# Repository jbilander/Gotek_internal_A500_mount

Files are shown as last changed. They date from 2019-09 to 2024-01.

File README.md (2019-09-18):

# Gotek_internal_A500_mount
An internal Gotek mounting bracket for the Amiga 500 designed in DesignSpark Mechanical 4.0

I was not happy with the internal mount I got when buying a Gotek floppy emulator for the Amiga 500. I did a respin to better position the usb socket and the oled display, and to fit both the revision A and B of the A500/500+ Cases. This is the result. You don't have to modify your case in any way for the Gotek to fit with this mount, and the standard 34-pin floppy cable can be used as it just about reaches the Gotek. It sits a few mm back compared to the other mount.

<a href="images/Gotek_internal_A500_mount_pic1.jpg">
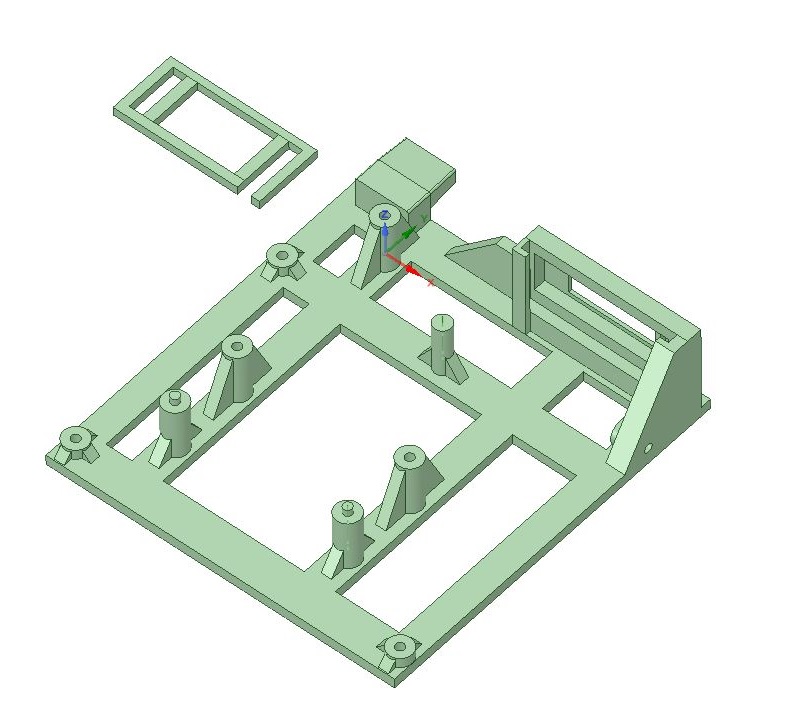
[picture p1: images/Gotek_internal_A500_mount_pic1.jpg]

</a>

***

To 3d-print this model it takes about 5 hours with Standard Quality 0.2mm, 60% infill, using an Ender 3 Pro printer. It uses around 12 meters Ø1.75mm (35 grams) of filament.

<a href="images/Gotek_internal_A500_mount_pic2.jpg">
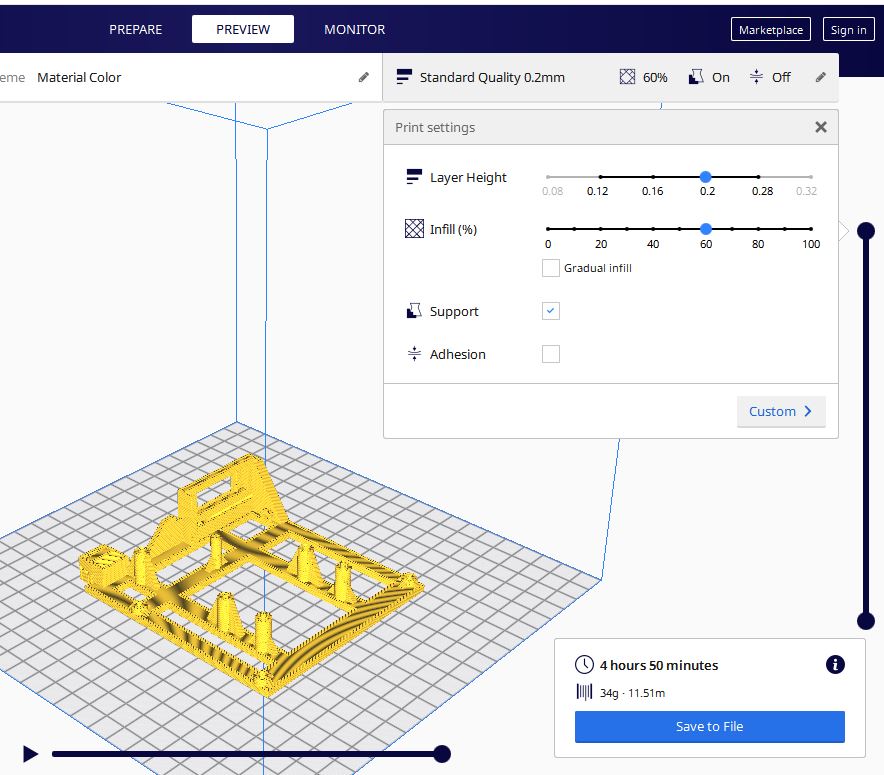
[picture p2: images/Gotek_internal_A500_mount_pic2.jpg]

</a>
<br />
<a href="images/Gotek_internal_A500_mount_pic3.jpg">
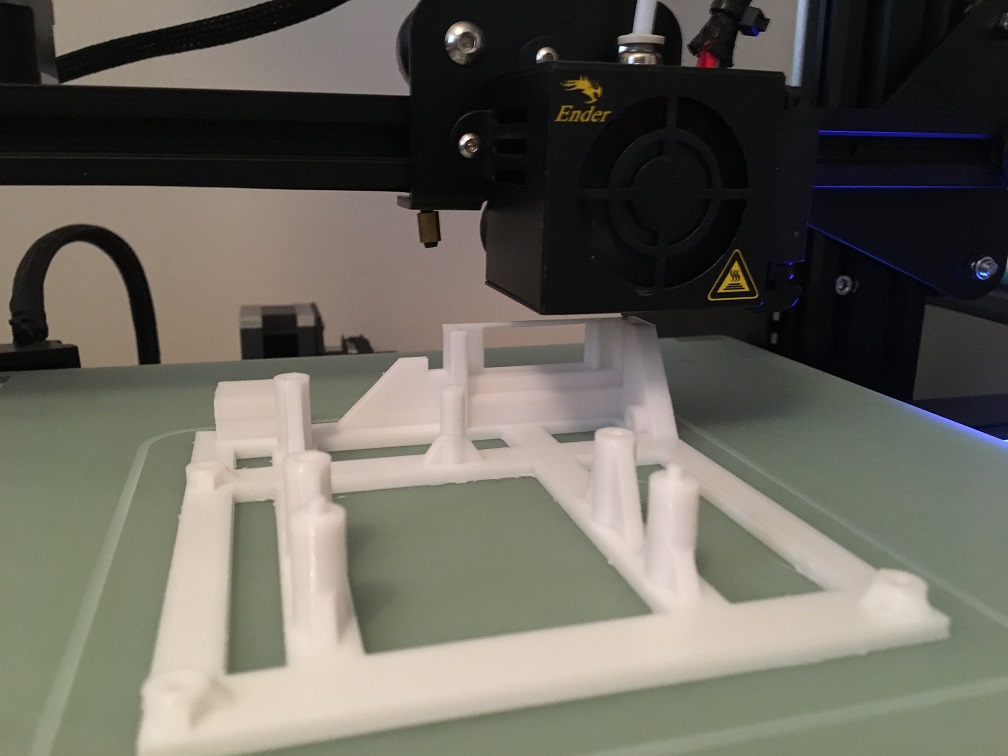
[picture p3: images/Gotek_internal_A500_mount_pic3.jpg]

</a>

***
The result of the printout, the little plastic piece is used to secure the oled display and keep it in its housing.

<a href="images/Gotek_internal_A500_mount_pic4.jpg">
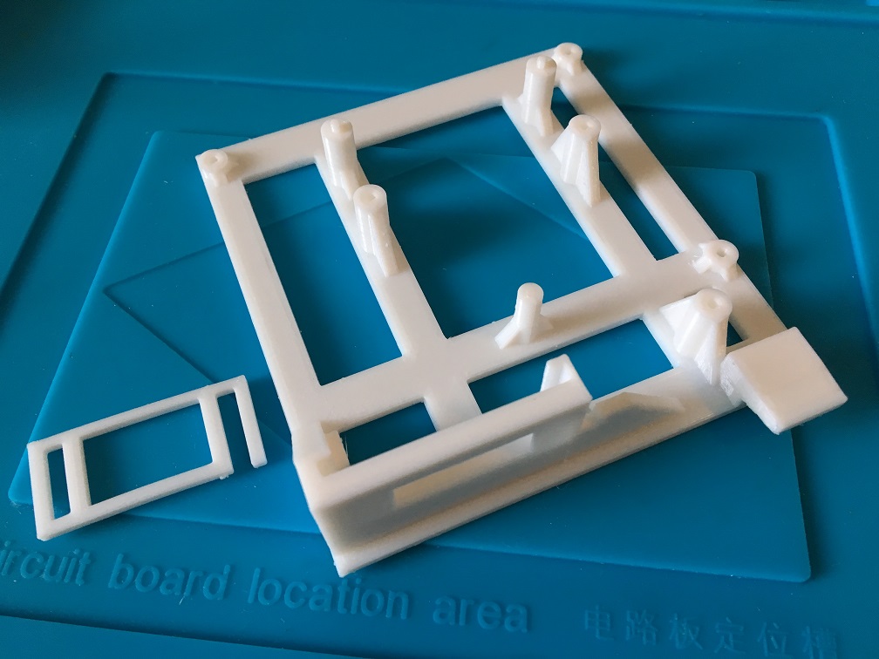
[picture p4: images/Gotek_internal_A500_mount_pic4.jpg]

</a>
<a href="images/Gotek_internal_A500_mount_pic5.jpg">
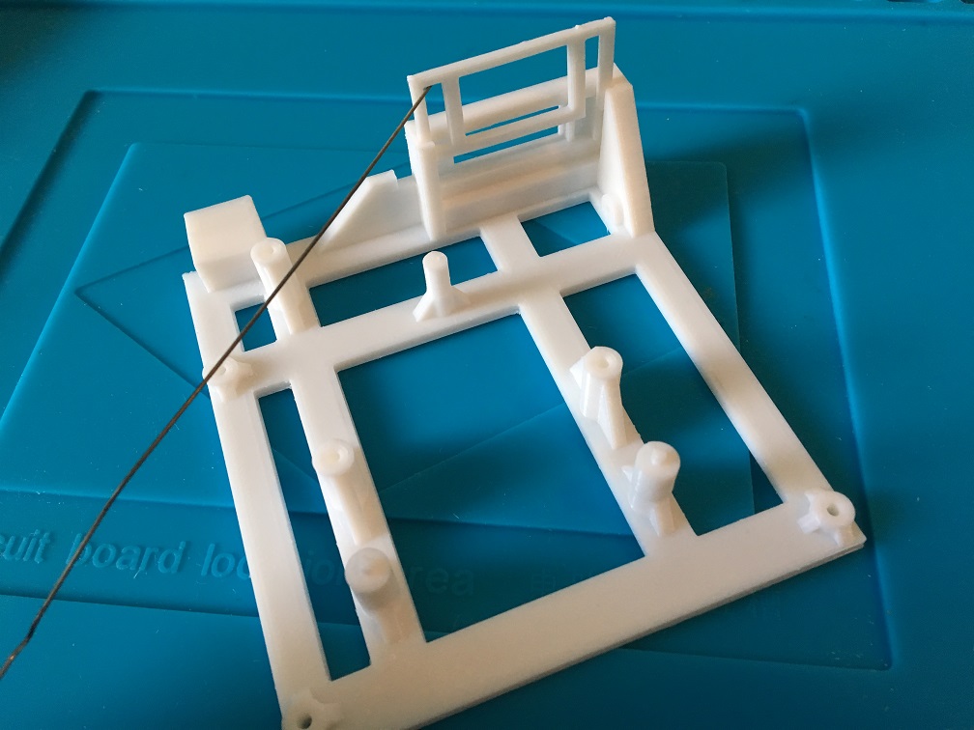
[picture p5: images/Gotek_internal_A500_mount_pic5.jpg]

</a>

***

Add two standoffs, one on each side of the rear side of the mount. Use an Iron to heat the little badger up and push it in a bit as the plastic melts, then screw it in the last bit until firmly seated in end position. The standoff is 8mm high (~12mm with the screw part included).

<a href="images/Gotek_internal_A500_mount_pic6.jpg">
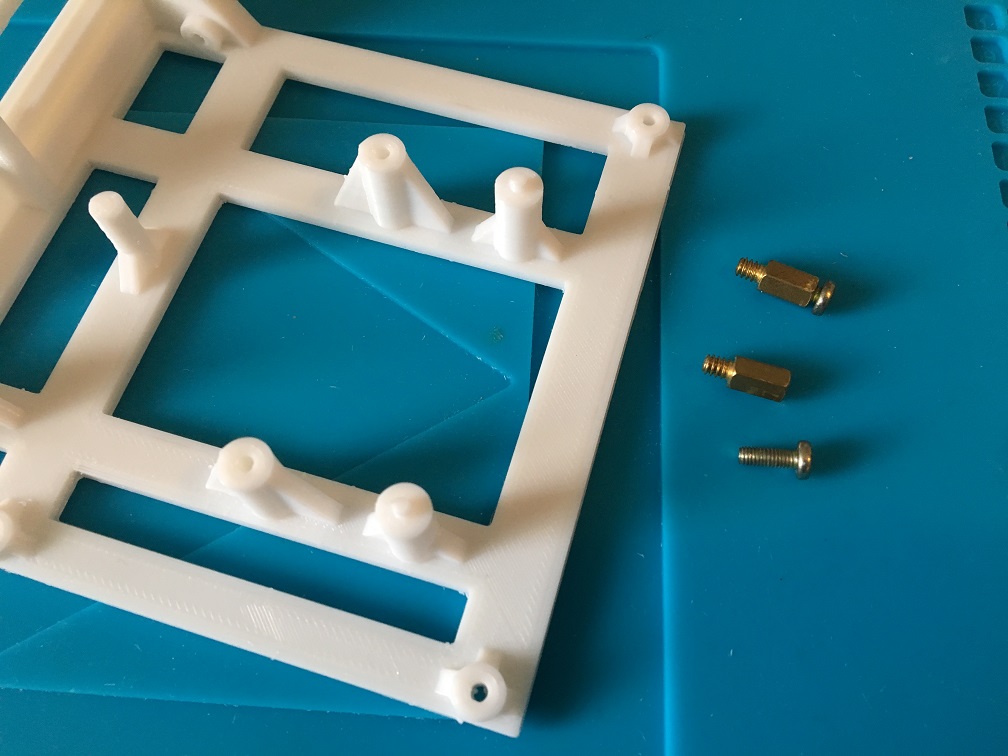
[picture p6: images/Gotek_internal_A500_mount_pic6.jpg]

</a>
<a href="images/Gotek_internal_A500_mount_pic7.jpg">
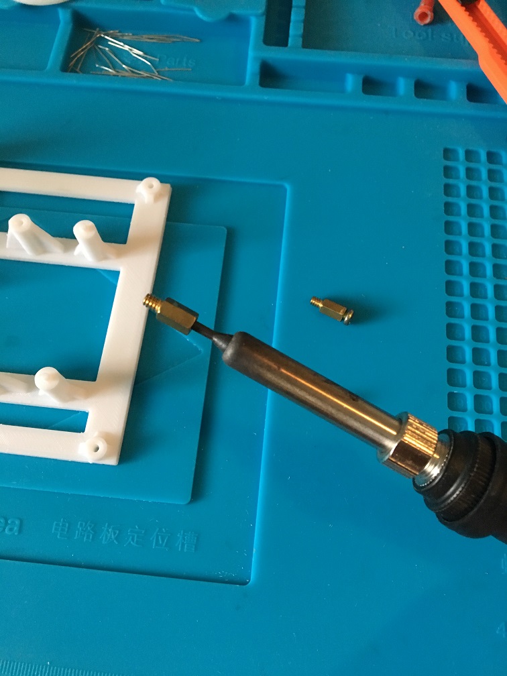
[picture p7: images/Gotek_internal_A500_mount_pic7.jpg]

</a>
<a href="images/Gotek_internal_A500_mount_pic8.jpg">
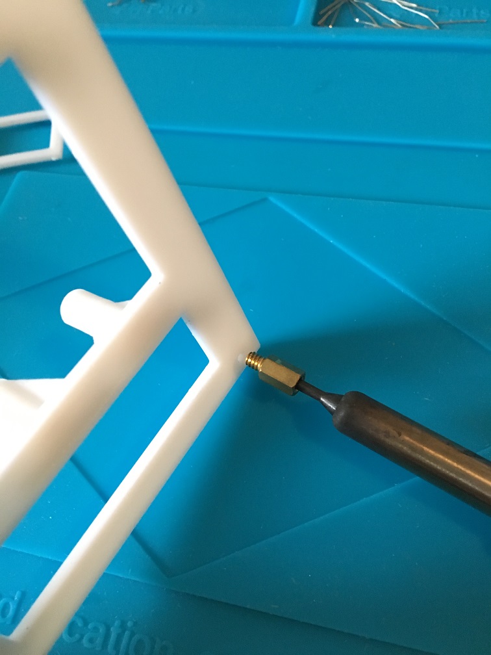
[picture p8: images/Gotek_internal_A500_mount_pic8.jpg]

</a>
<br />
<a href="images/Gotek_internal_A500_mount_pic9.jpg">
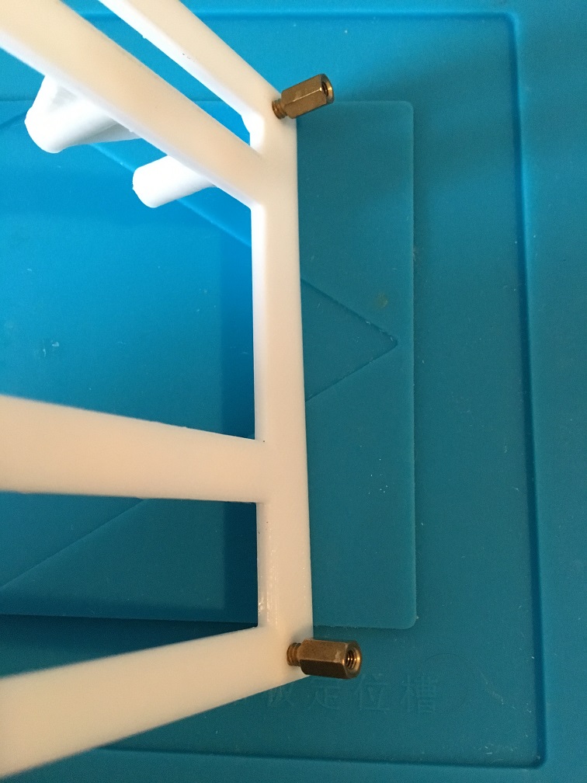
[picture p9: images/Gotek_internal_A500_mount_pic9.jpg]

</a>
<a href="images/Gotek_internal_A500_mount_pic10.jpg">
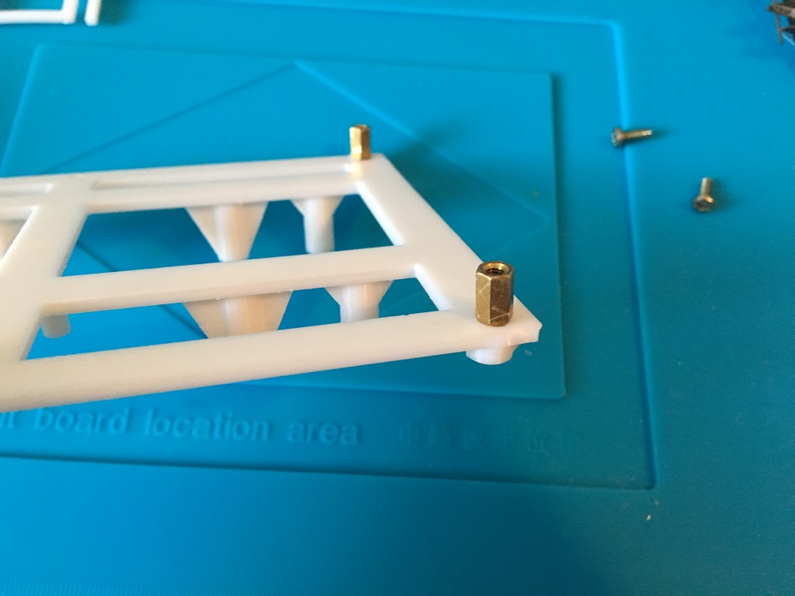
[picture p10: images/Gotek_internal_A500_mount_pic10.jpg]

</a>
<a href="images/Gotek_internal_A500_mount_pic11.jpg">
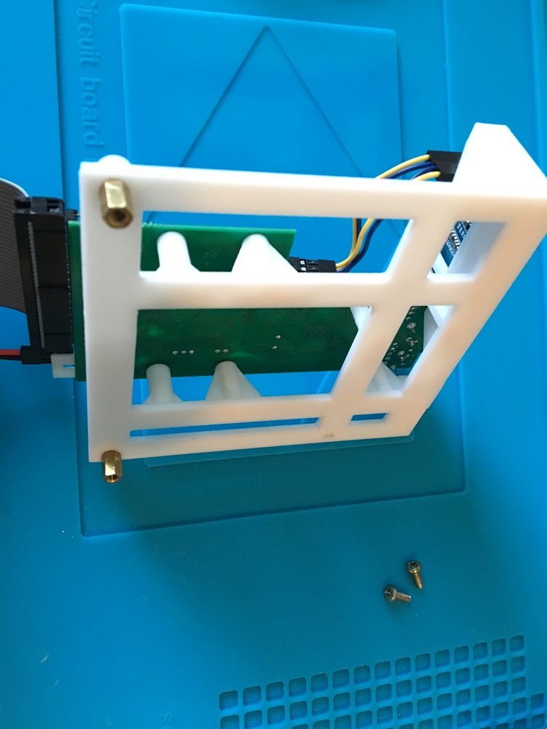
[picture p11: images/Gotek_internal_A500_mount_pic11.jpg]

</a>

***

Now fit the Gotek pcb in the mount and put three screws (black in picture) to tighten it. Fit the display by gently pressing it into place and put the little plastic piece as a stopper behind it.

<a href="images/Gotek_internal_A500_mount_pic12.jpg">
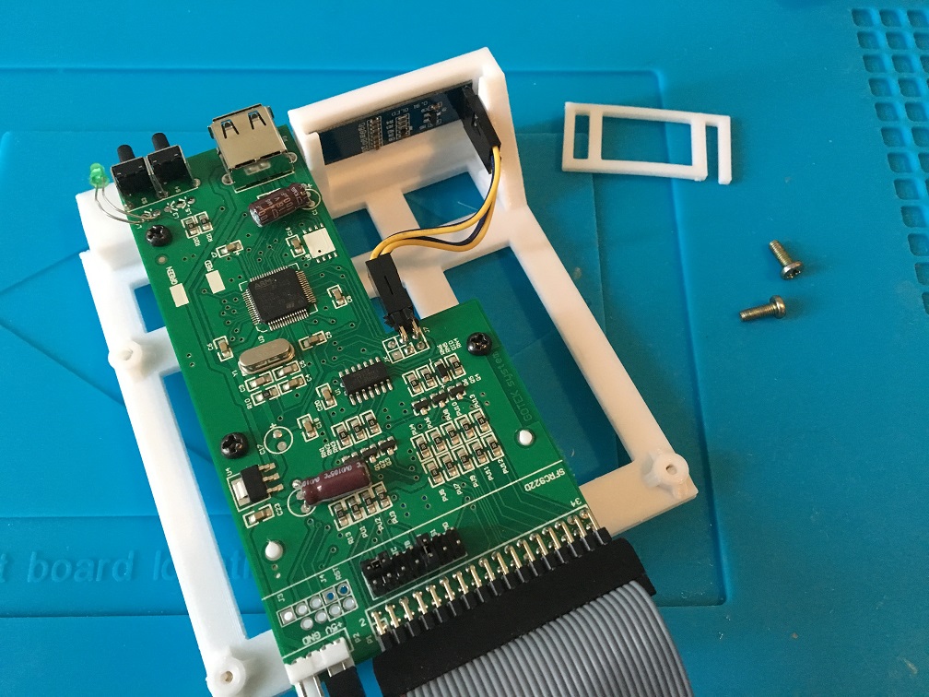
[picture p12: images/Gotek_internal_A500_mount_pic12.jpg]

</a>
<a href="images/Gotek_internal_A500_mount_pic13.jpg">
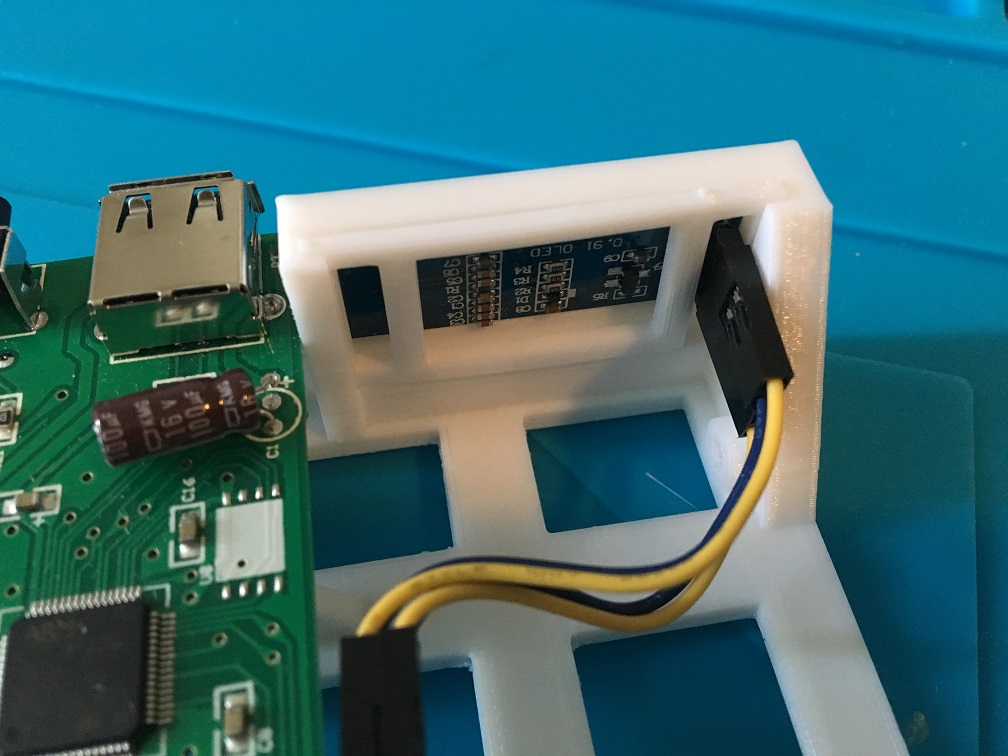
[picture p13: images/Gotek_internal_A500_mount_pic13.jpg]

</a>
<a href="images/Gotek_internal_A500_mount_pic14.jpg">
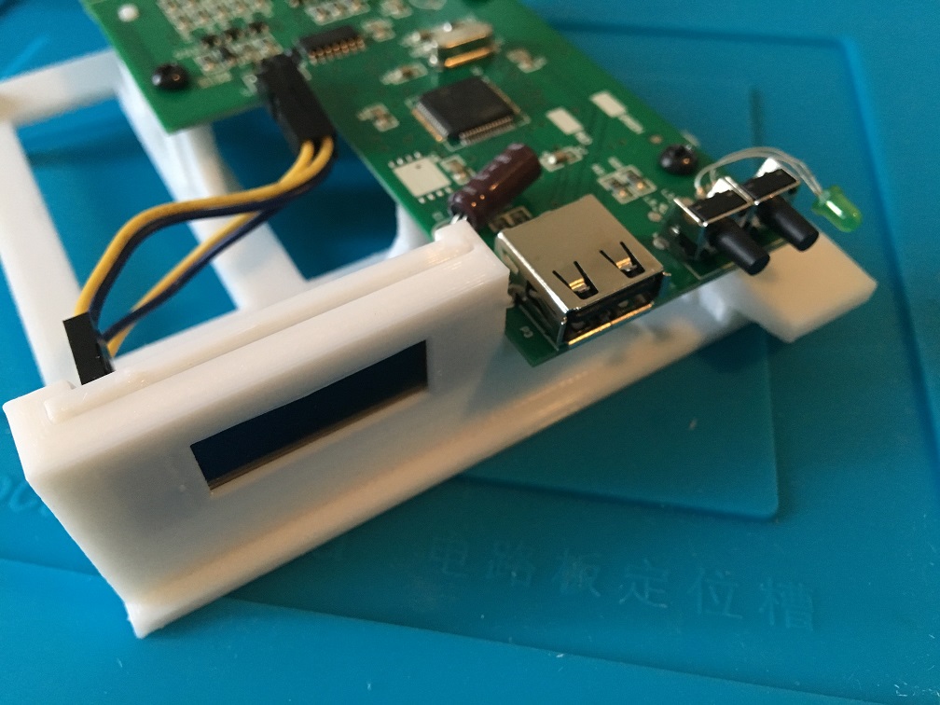
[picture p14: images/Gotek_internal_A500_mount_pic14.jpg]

</a>

***

Now time to see how well this new mount + Gotek fits in the different A500 Cases.

<a href="images/A500_Case_revA_vs_revB.jpg">
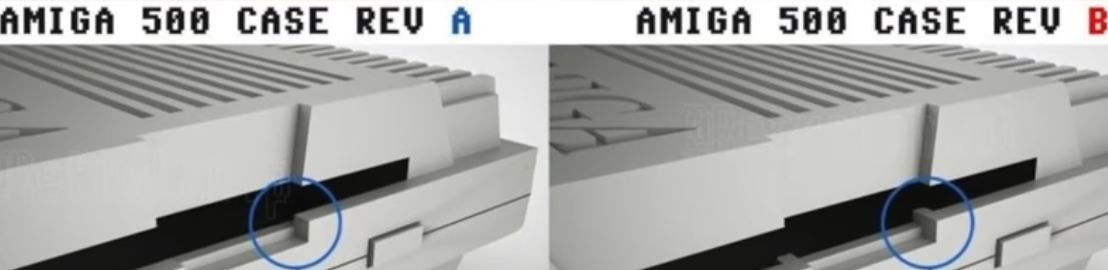
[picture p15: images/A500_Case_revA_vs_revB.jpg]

</a>
<br />

First let's try to fit it in a REV B Case, this is A500+ and the A500s with the rectangular "Commodore A-500" badge on case:

<a href="images/Gotek_internal_A500_mount_pic15.jpg">
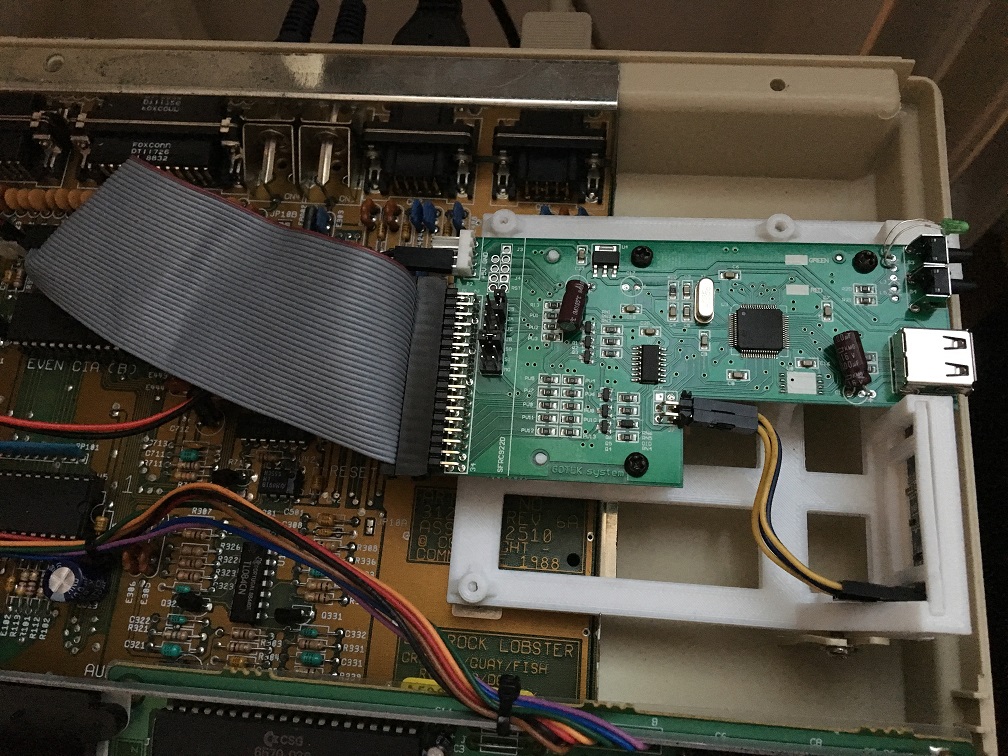
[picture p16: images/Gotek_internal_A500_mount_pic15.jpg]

</a>
<a href="images/Gotek_internal_A500_mount_pic16.jpg">
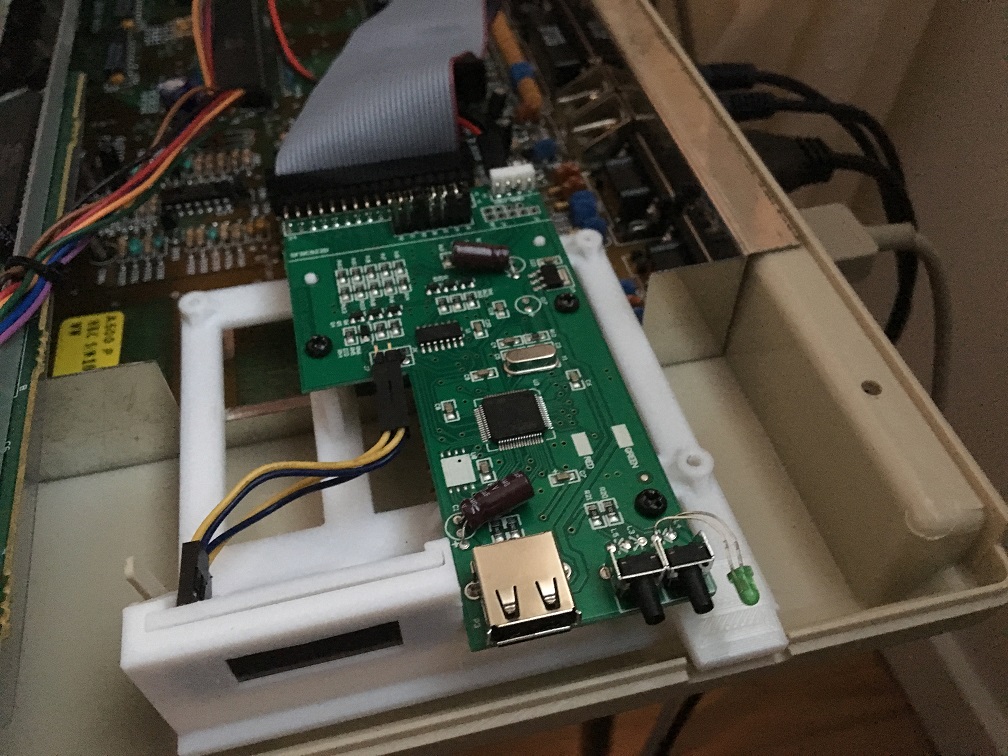
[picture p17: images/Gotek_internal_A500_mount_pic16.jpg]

</a>
<a href="images/Gotek_internal_A500_mount_pic17.jpg">
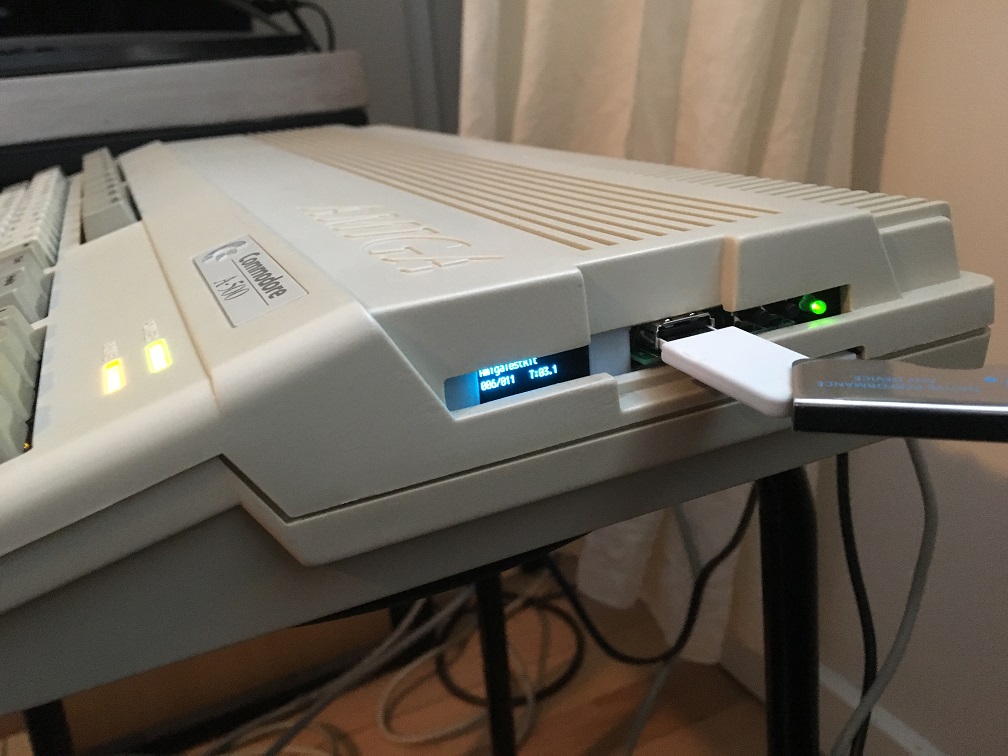
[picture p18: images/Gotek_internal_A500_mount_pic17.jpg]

</a>
<a href="images/Gotek_internal_A500_mount_pic18.jpg">
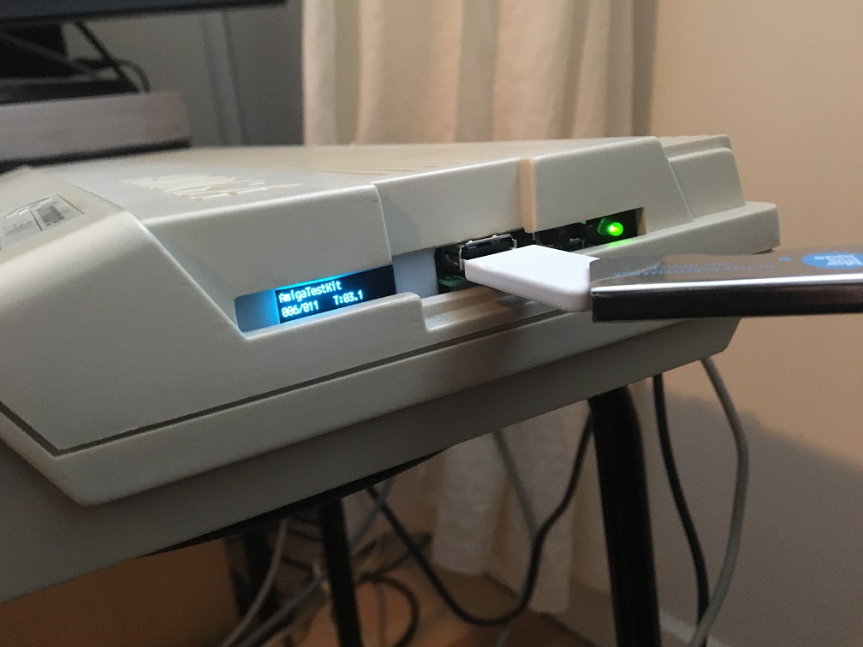
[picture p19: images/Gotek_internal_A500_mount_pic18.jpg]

</a>

***

Nice, and now in a REV A Case:

<a href="images/Gotek_internal_A500_mount_pic19.jpg">
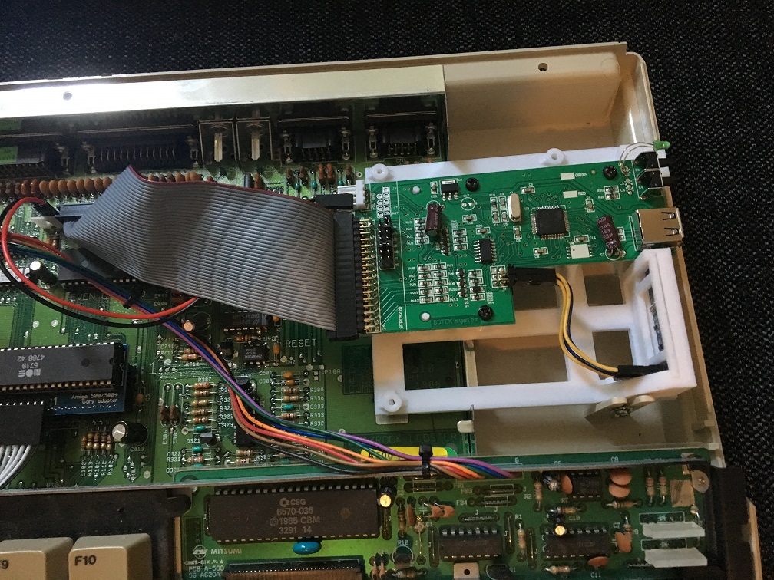
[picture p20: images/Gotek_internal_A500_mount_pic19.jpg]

</a>
<a href="images/Gotek_internal_A500_mount_pic20.jpg">
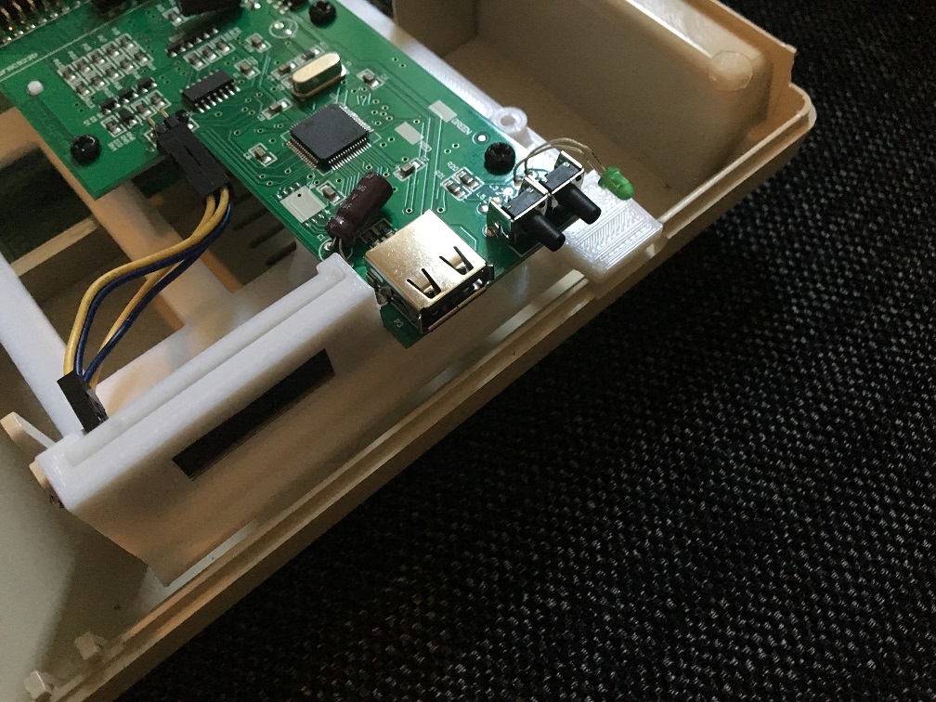
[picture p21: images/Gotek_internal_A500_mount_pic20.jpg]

</a>
<a href="images/Gotek_internal_A500_mount_pic21.jpg">
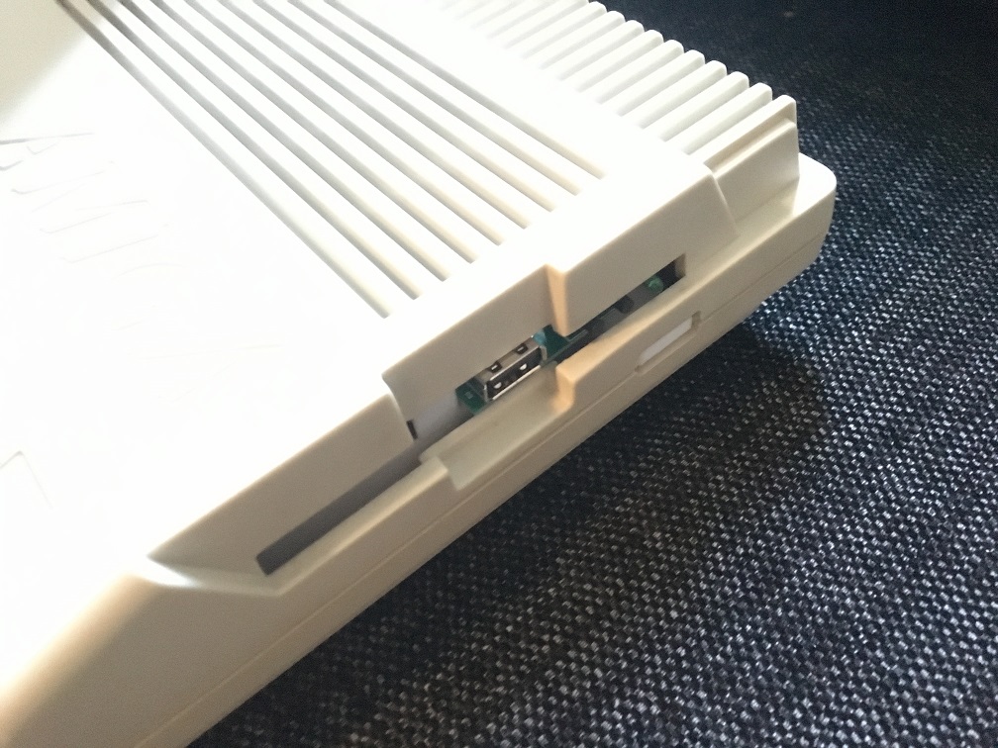
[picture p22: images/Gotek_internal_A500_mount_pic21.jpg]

</a>
<a href="images/Gotek_internal_A500_mount_pic22.jpg">
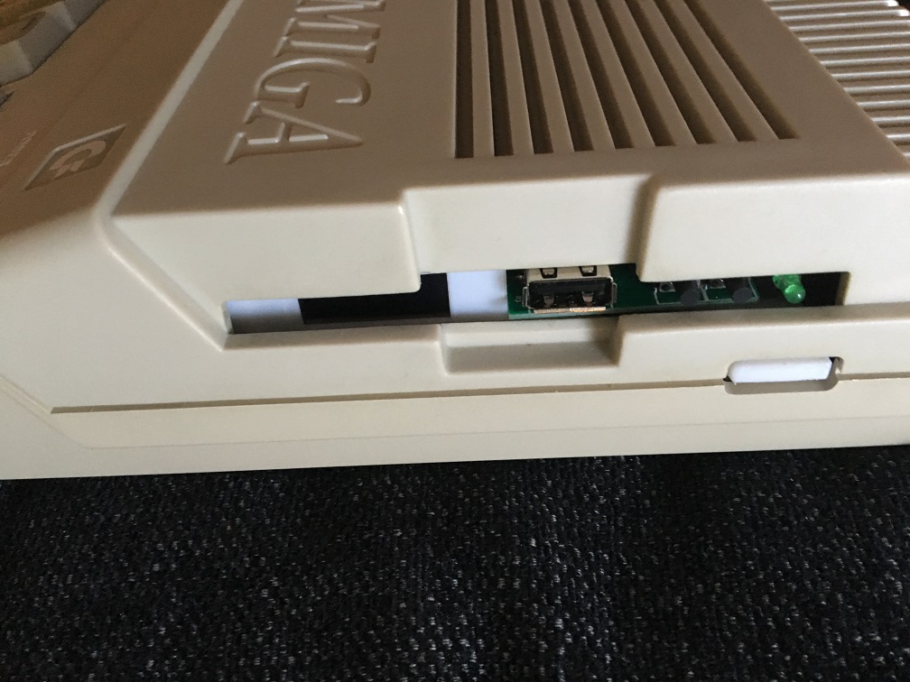
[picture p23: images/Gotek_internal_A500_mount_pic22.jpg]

</a>

Sweet!, A snug fit there as well, and no problem closing either of the cases. Mission accomplished!

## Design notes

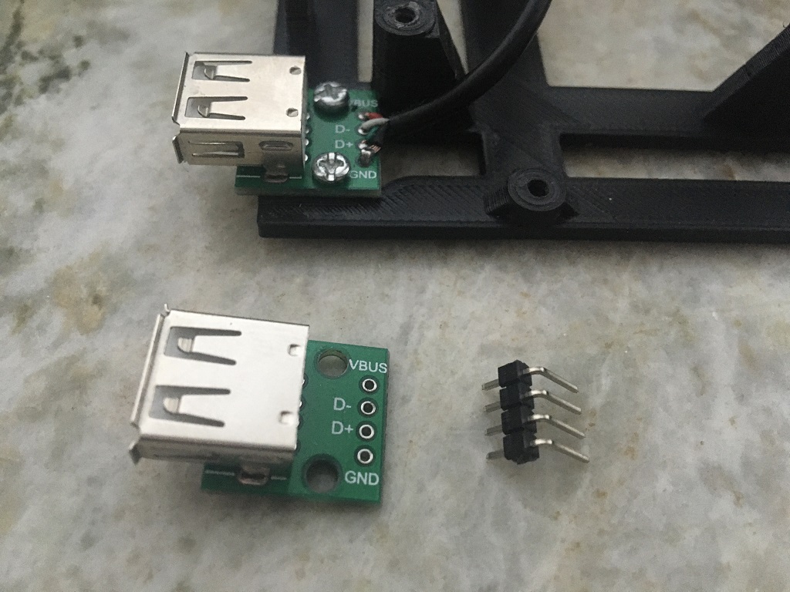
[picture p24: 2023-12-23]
images/Gotek_internal_a500_mounting_bracket_i2c_usb_pic3.jpg

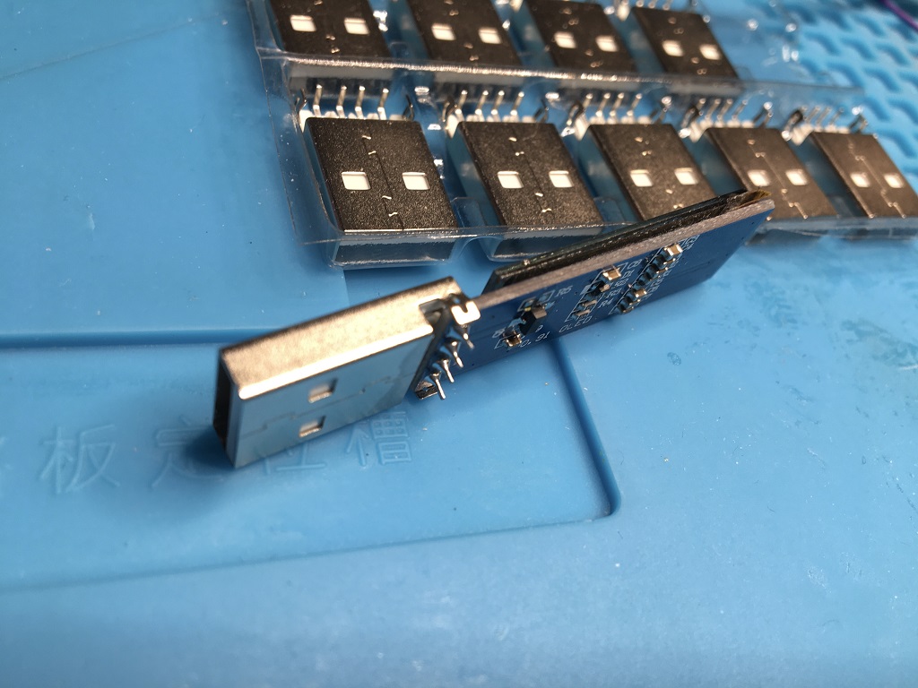
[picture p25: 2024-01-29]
images/Gotek_internal_a500_mounting_bracket_i2c_usb_pic13.jpg

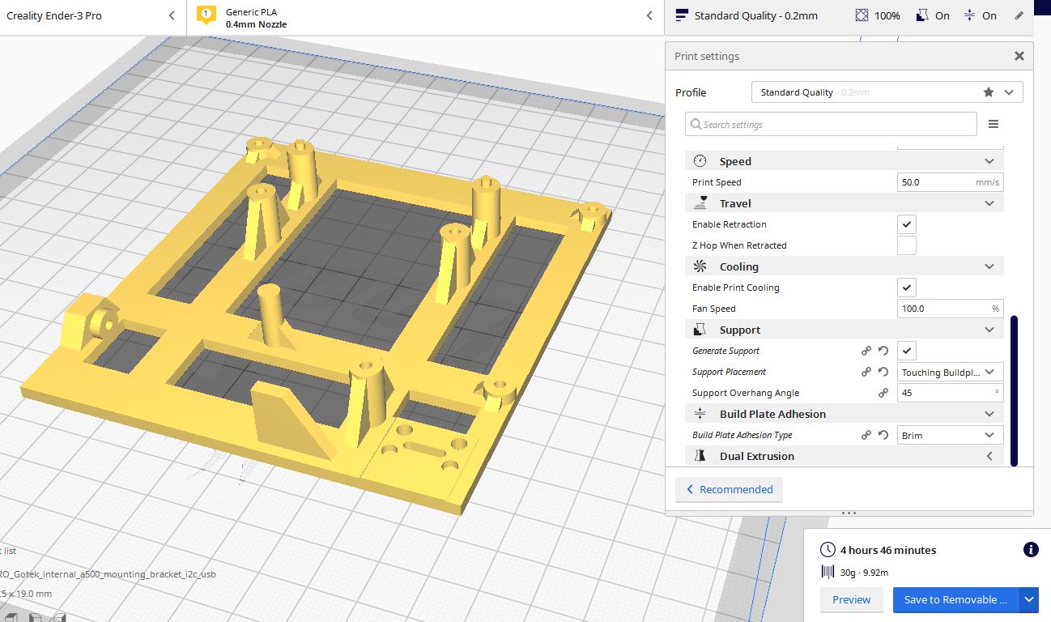
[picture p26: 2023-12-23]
images/Gotek_internal_a500_mounting_bracket_i2c_usb_pic1.jpg

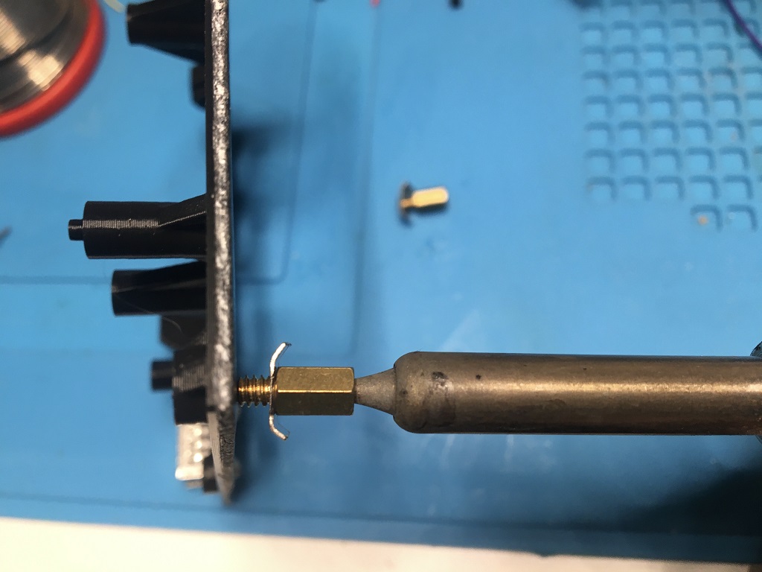
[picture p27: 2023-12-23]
images/Gotek_internal_a500_mounting_bracket_i2c_usb_pic6.jpg

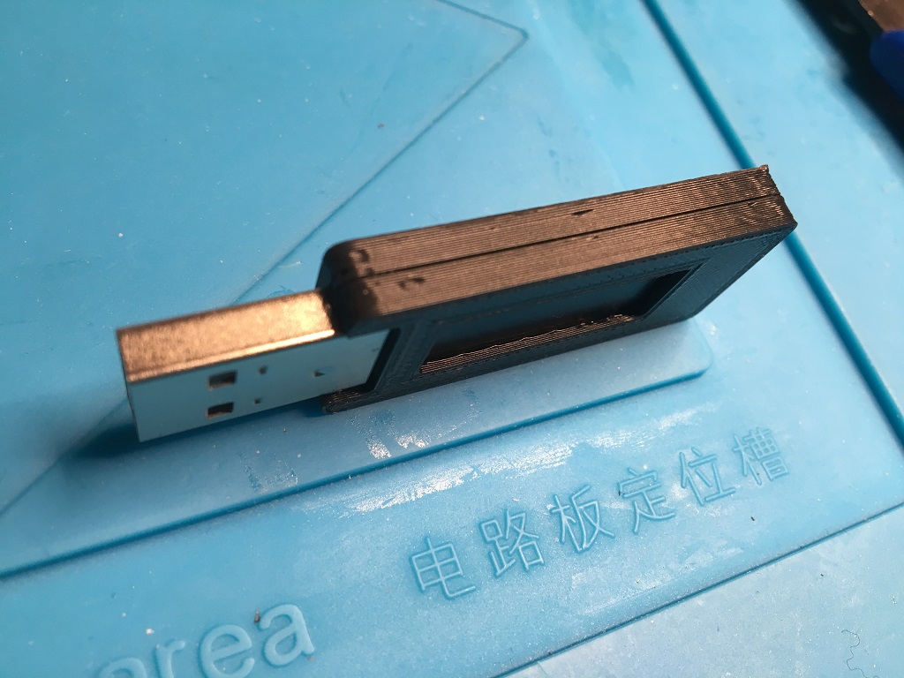
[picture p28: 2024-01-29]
images/Gotek_internal_a500_mounting_bracket_i2c_usb_pic17.jpg

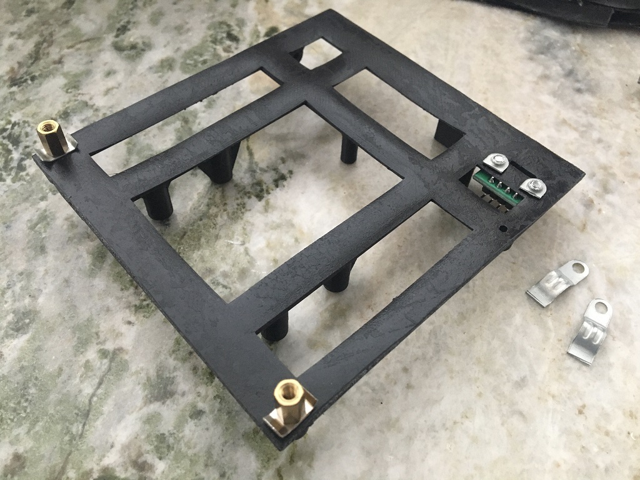
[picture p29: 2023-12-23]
images/Gotek_internal_a500_mounting_bracket_i2c_usb_pic8.jpg

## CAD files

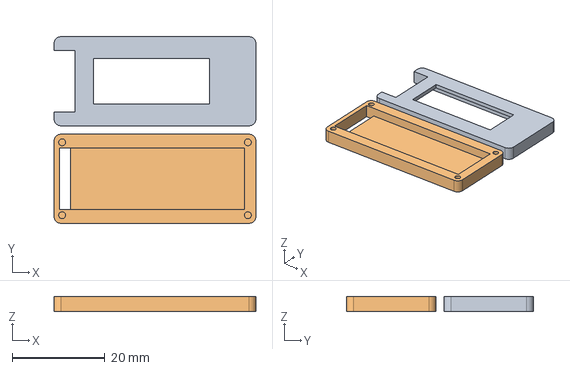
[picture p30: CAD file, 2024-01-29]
Gotek_lcd_display_cover.stp
43.5 x 40.2 x 3.25 mm

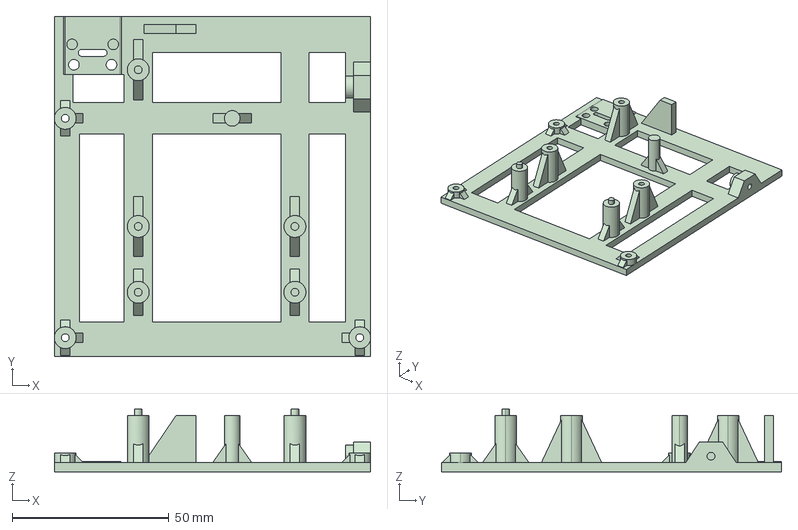
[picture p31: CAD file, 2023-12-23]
Gotek_internal_a500_mounting_bracket_i2c_usb.stp
101.0 x 108.5 x 20.0 mm

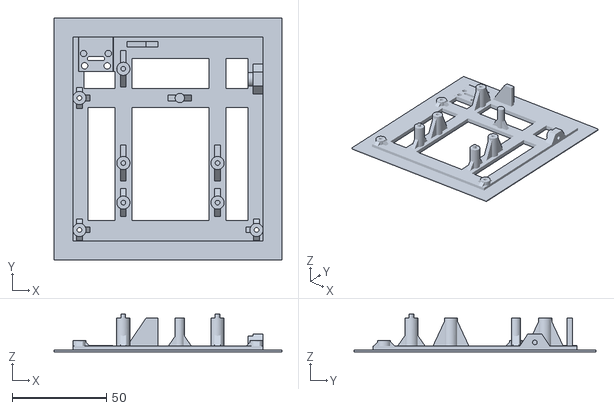
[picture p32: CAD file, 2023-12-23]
Gotek_internal_a500_mounting_bracket_i2c_usb_with_brim.stl
121.0 x 128.5 x 20.0

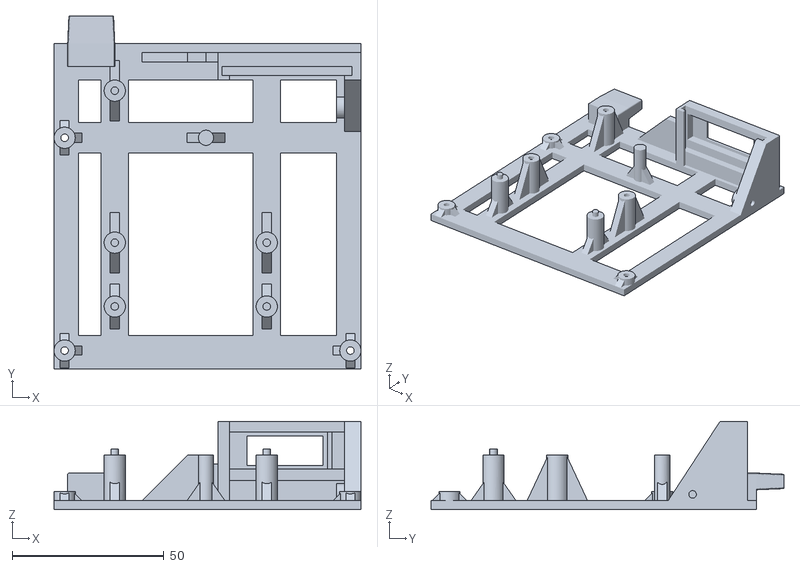
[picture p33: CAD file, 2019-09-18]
Gotek_internal_A500_mount.stl
101.0 x 116.0 x 29.0

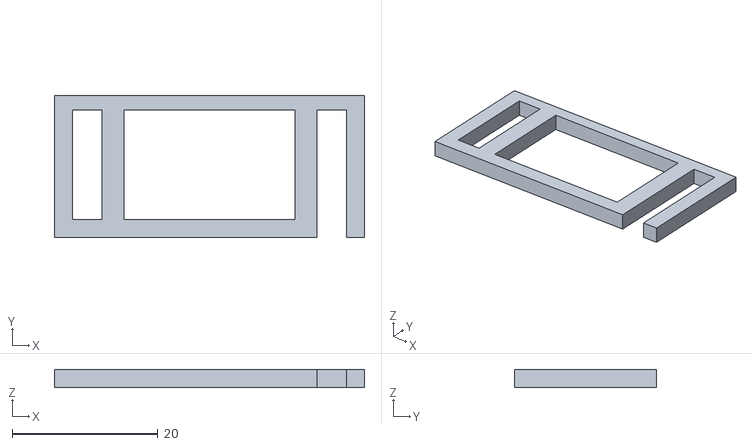
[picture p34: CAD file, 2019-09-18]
Gotek_internal_A500_display_stopper.stl
42.5 x 19.5 x 2.50

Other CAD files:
Gotek_internal_a500_mounting_bracket_usb.stp
Gotek_internal_a500_mounting_bracket_usb_with_brim.stl
Gotek_internal_a500_mounting_bracket_i2c_usb.stl
Gotek_internal_a500_mounting_bracket_usb.stl
Gotek_lcd_display_cover.stl

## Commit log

2019-09-18 added images and source
    [Gotek_internal_A500_display_stopper.stl, Gotek_internal_A500_mount.stl]
2023-12-23 Add source files for new design
    [Gotek_internal_a500_mounting_bracket_i2c_usb.stl, Gotek_internal_a500_mounting_bracket_i2c_usb.stp, Gotek_internal_a500_mounting_bracket_i2c_usb_with_brim.stl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]
2024-01-29 Added files for lcd display cover
    [Gotek_lcd_display_cover.stl, Gotek_lcd_display_cover.stp]
